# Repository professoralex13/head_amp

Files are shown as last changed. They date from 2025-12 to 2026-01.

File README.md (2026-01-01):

# CosplayCore

TODO: Put information about it here

## IMPORTANT NOTES:
Main board V1.0 runs ADC data from a CODEC into GPIO12 which also serves as a strapping pin. This signal is pulled high by the CODEC resulting in the ESP32 booting with a flash chip voltage is 1.8V which is incorrect.
To work around this, the following command must be run:
```espefuse --port [PORT] burn-efuse XPD_SDIO_REG 1 XPD_SDIO_TIEH 1 XPD_SDIO_FORCE 1```

This overrides the strapping pin so the memory supply voltage is permenantly set at 3.3V.
Until this comand is run and the fuses are burned on the ESP32, it cannot be flashed with any code.

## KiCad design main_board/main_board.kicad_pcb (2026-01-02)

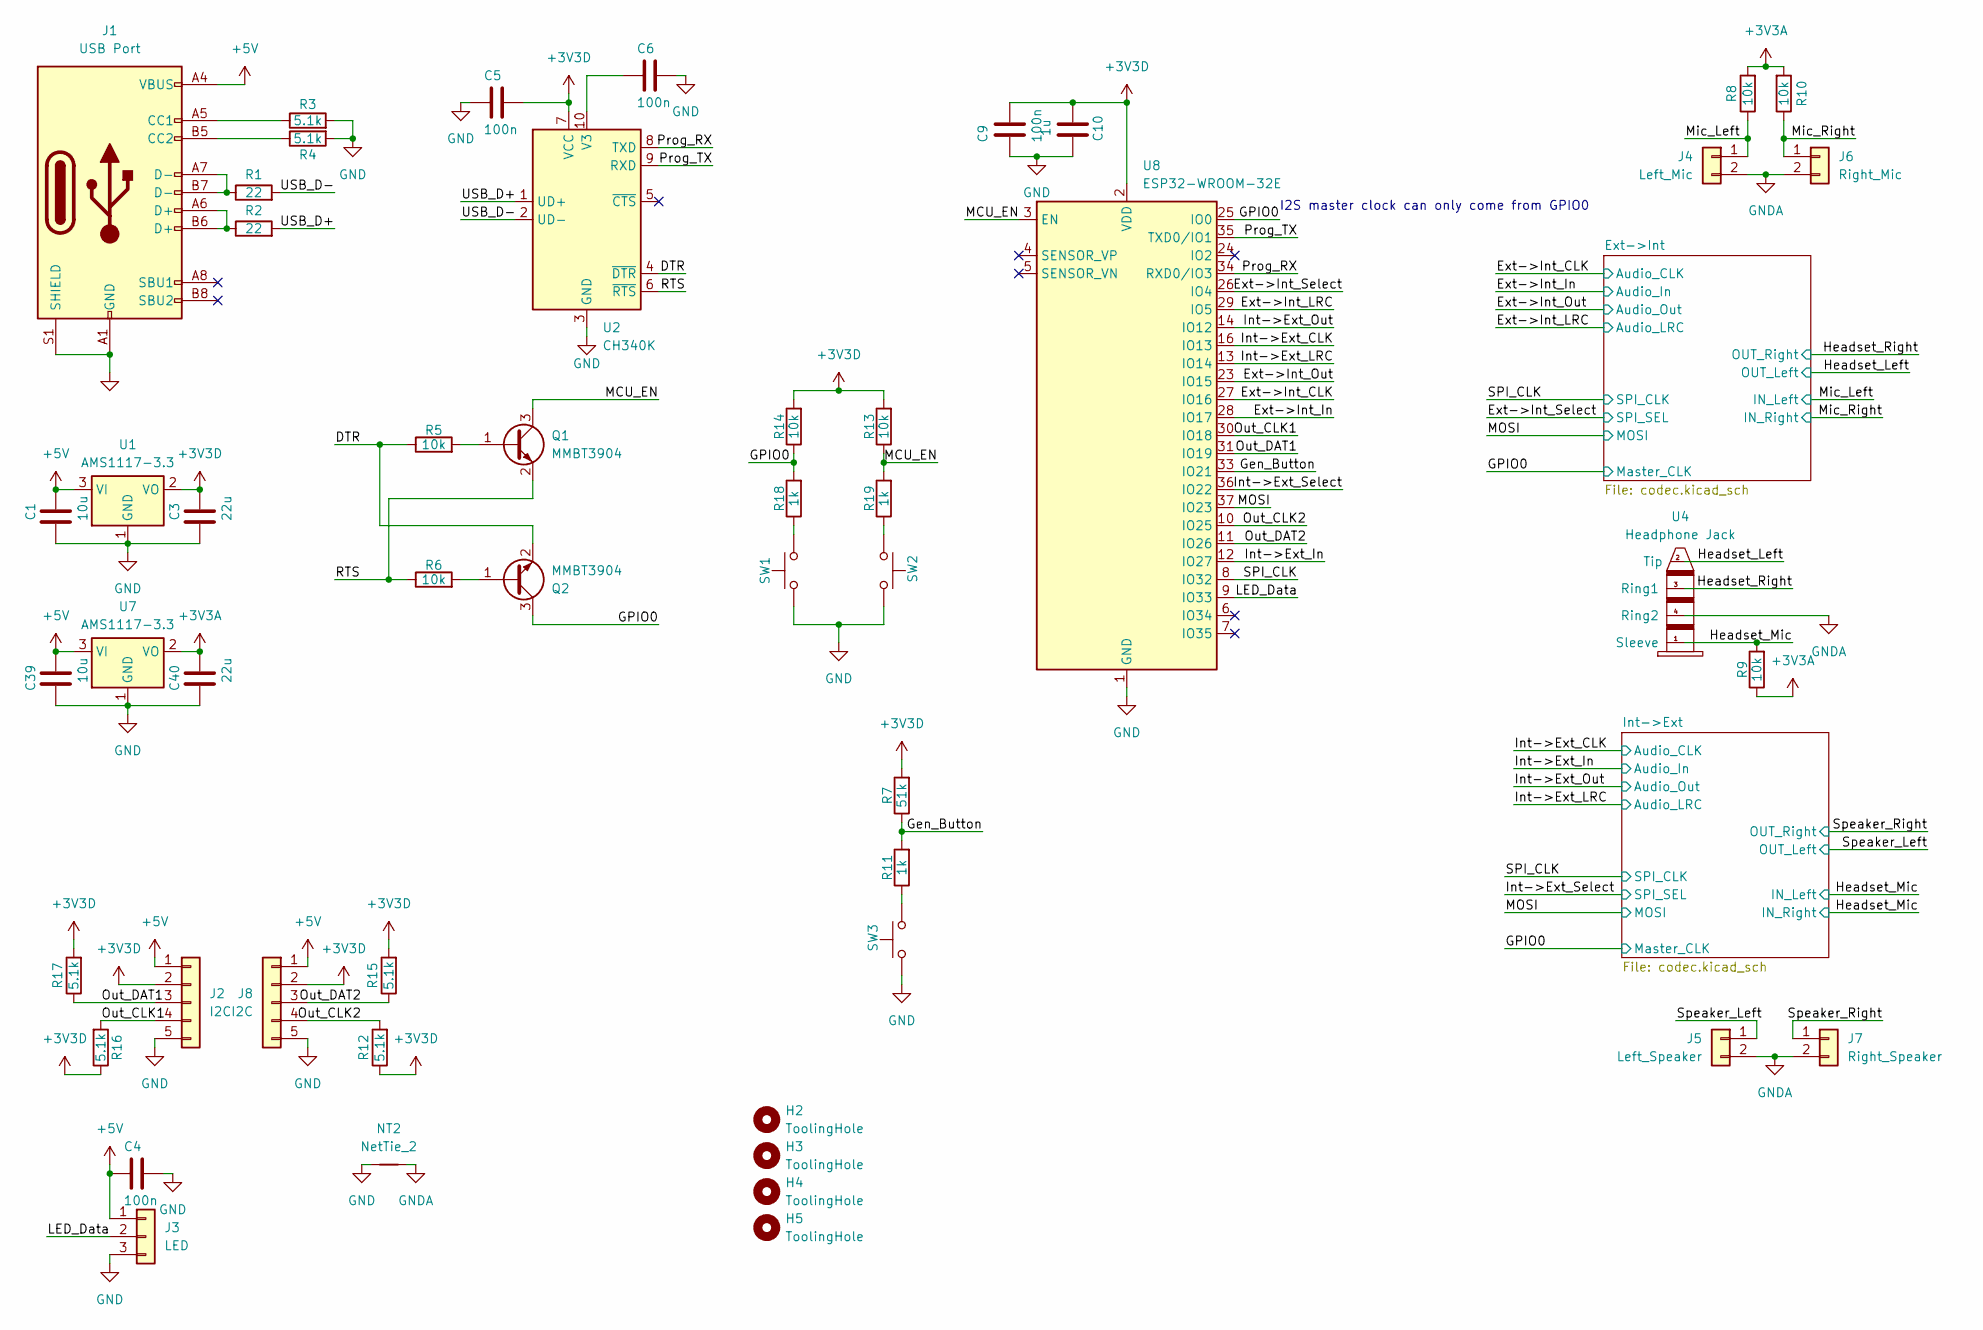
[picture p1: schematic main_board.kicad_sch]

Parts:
C1, C39: 10u; C_0603_1608Metric; LCSC C19702
C3, C40: 22u; C_0603_1608Metric; LCSC C59461
C4, C5, C6: 100n; C_0402_1005Metric; LCSC C307331
C9: 100n; C_0603_1608Metric; LCSC C14663
C10: 1u; C_0603_1608Metric; LCSC C15849
H2, H3, H4, H5: ToolingHole; ToolingHole_1.152mm
J1: USB Port; USB_C_Receptacle_GCT_USB4105-xx-A_16P_TopMnt_Horizontal; LCSC C2927038
J2, J8: I2C; JST_EH_S5B-EH_1x05_P2.50mm_Horizontal; LCSC C265103
J3: LED; JST_EH_S3B-EH_1x03_P2.50mm_Horizontal; LCSC C263754
J4: Left_Mic; JST_EH_S2B-EH_1x02_P2.50mm_Horizontal; LCSC C514173
J5: Left_Speaker; JST_EH_S2B-EH_1x02_P2.50mm_Horizontal; LCSC C514173
J6: Right_Mic; JST_EH_S2B-EH_1x02_P2.50mm_Horizontal; LCSC C514173
J7: Right_Speaker; JST_EH_S2B-EH_1x02_P2.50mm_Horizontal; LCSC C514173
NT2: NetTie_2; NetTie-2_SMD_Pad2.0mm
Q1, Q2: MMBT3904; SOT-23; LCSC C20526
R1, R2: 22; R_0402_1005Metric; LCSC C25092
R3, R4, R12, R15, R16, R17: 5.1k; R_0402_1005Metric; LCSC C25905
R5, R6, R8, R9, R10, R13, R14: 10k; R_0402_1005Metric; LCSC C25744
R7: 51k; R_0402_1005Metric; LCSC C25794
R11, R18, R19: 1k; R_0402_1005Metric; LCSC C11702
SW1, SW2, SW3: SW_Push; SW_SPST_TS-1088-xR020; LCSC C720477
U1, U7: AMS1117-3.3; SOT-223-3_TabPin2; LCSC C6186
U2: CH340K; SSOP-10-1EP_3.9x4.9mm_P1mm_EP2.1x3.3mm; LCSC C18208922
U4: Headphone Jack; PJ-320A; LCSC C2884926
U8: ESP32-WROOM-32E; LCSC C701342

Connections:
+3V3A: C40.2, R8.2, R9.1, R10.2, U7.2 (VO); also elsewhere on the board
+3V3D: C3.2, C5.2, C9.2, C10.1, J2.2, J8.2, R7.2, R12.1, R13.2, R14.2, R15.2, R16.1, R17.2, U1.2 (VO), U2.7 (VCC), U8.2 (VDD); also elsewhere on the board
+5V: C1.2, C4.1, C39.2, J1.A4 (VBUS), J1.A9 (VBUS), J1.B4 (VBUS), J1.B9 (VBUS), J2.1, J3.1, J8.1, U1.3 (VI), U7.3 (VI)
/DTR: Q2.2 (E), R5.1, U2.4 (~DTR)
/Ext->Int_CLK: U8.27 (IO16); also elsewhere on the board
/Ext->Int_In: U8.28 (IO17); also elsewhere on the board
/Ext->Int_LRC: U8.29 (IO5); also elsewhere on the board
/Ext->Int_Out: U8.23 (IO15); also elsewhere on the board
/Ext->Int_Select: U8.26 (IO4); also elsewhere on the board
/GPIO0: Q2.3 (C), R14.1, R18.2, U8.25 (IO0); also elsewhere on the board
/Gen_Button: R7.1, R11.2, U8.33 (IO21)
/Headset_Left: U4.2 (Tip); also elsewhere on the board
/Headset_Mic: R9.2, U4.1 (Sleeve); also elsewhere on the board
/Headset_Right: U4.3 (Ring1); also elsewhere on the board
/Int->Ext_CLK: U8.16 (IO13); also elsewhere on the board
/Int->Ext_In: U8.12 (IO27); also elsewhere on the board
/Int->Ext_LRC: U8.13 (IO14); also elsewhere on the board
/Int->Ext_Out: U8.14 (IO12); also elsewhere on the board
/Int->Ext_Select: U8.36 (IO22); also elsewhere on the board
/LED_Data: J3.2, U8.9 (IO33)
/MCU_EN: Q1.3 (C), R13.1, R19.2, U8.3 (EN)
/MOSI: U8.37 (IO23); also elsewhere on the board
/Mic_Left: J4.1, R8.1; also elsewhere on the board
/Mic_Right: J6.1, R10.1; also elsewhere on the board
/Out_CLK1: J2.4, R16.2, U8.30 (IO18)
/Out_CLK2: J8.4, R12.2, U8.10 (IO25)
/Out_DAT1: J2.3, R17.1, U8.31 (IO19)
/Out_DAT2: J8.3, R15.1, U8.11 (IO26)
/Prog_RX: U2.8 (TXD), U8.34 (RXD0/IO3)
/Prog_TX: U2.9 (RXD), U8.35 (TXD0/IO1)
/RTS: Q1.2 (E), R6.1, U2.6 (~RTS)
/SPI_CLK: U8.8 (IO32); also elsewhere on the board
/Speaker_Left: J5.1; also elsewhere on the board
/Speaker_Right: J7.1; also elsewhere on the board
/USB_D+: R2.2, U2.1 (UD+)
/USB_D-: R1.2, U2.2 (UD-)
GND: C1.1, C3.1, C4.2, C5.1, C6.2, C9.1, C10.2, C39.1, C40.1, J1.A1 (GND), J1.A12 (GND), J1.B1 (GND), J1.B12 (GND), J1.S1 (SHIELD), J2.5, J3.3, J8.5, NT2.1, R3.2, R4.2, SW1.1, SW2.1, SW3.1, U1.1 (GND), U2.3 (GND), U2.11 (GND), U7.1 (GND), U8.1 (GND), U8.15 (GND), U8.38 (GND), U8.39 (GND); also elsewhere on the board
GNDA: J4.2, J5.2, J6.2, J7.2, NT2.2, U4.4 (Ring2); also elsewhere on the board
unnamed: J1.A5 (CC1), R3.1
unnamed: J1.B5 (CC2), R4.1
unnamed: J1.A6 (D+), J1.B6 (D+), R2.1
unnamed: J1.A7 (D-), J1.B7 (D-), R1.1
unnamed: Q1.1 (B), R5.2
unnamed: Q2.1 (B), R6.2
unnamed: R11.1, SW3.2
unnamed: R18.1, SW1.2
unnamed: R19.1, SW2.2
unnamed: C6.1, U2.10 (V3)

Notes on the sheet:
I2S master clock can only come from GPIO0

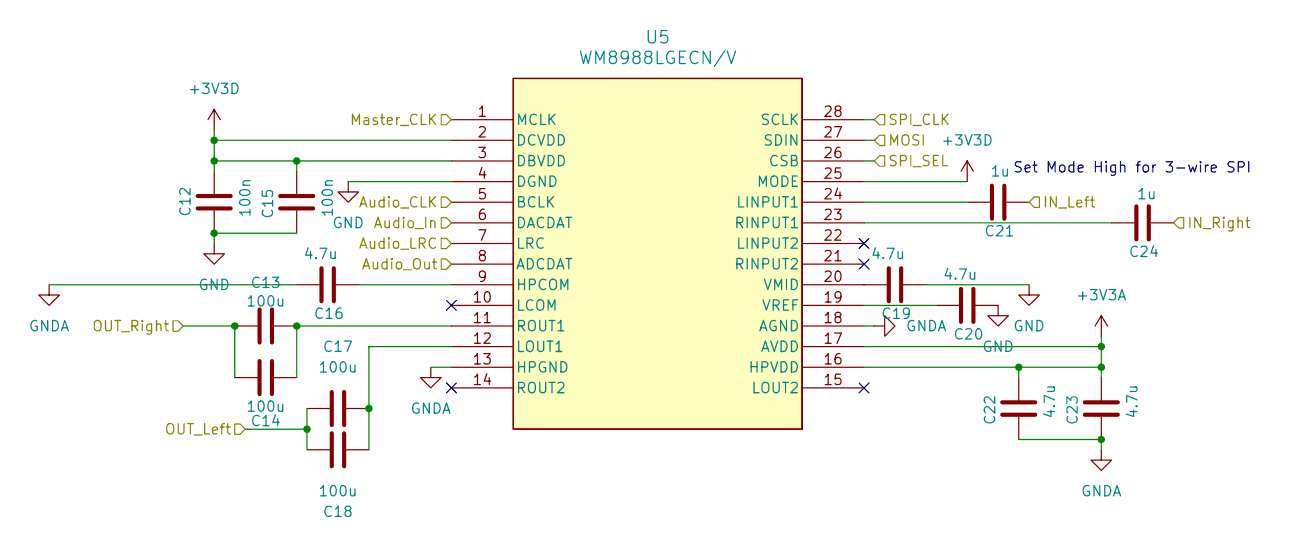
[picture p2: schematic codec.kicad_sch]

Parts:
C12, C15: 100n; C_0402_1005Metric; LCSC C307331
C13, C14, C17, C18: 100u; C_1206_3216Metric; LCSC C15008
C16, C19, C20, C22, C23: 4.7u; C_0402_1005Metric; LCSC C23733
C21, C24: 1u; C_0402_1005Metric; LCSC C52923
U5: WM8988LGECN/V; QFN28_4X4_CIR; LCSC C323851

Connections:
+3V3A: C22.2, C23.2, U5.16 (HPVDD), U5.17 (AVDD); also elsewhere on the board
+3V3D: C12.2, C15.2, U5.2 (DCVDD), U5.3 (DBVDD), U5.25 (MODE); also elsewhere on the board
/GPIO0: U5.1 (MCLK); also elsewhere on the board
/Headset_Mic: C21.1, C24.1; also elsewhere on the board
/Int->Ext_CLK: U5.5 (BCLK); also elsewhere on the board
/Int->Ext_In: U5.6 (DACDAT); also elsewhere on the board
/Int->Ext_LRC: U5.7 (LRC); also elsewhere on the board
/Int->Ext_Out: U5.8 (ADCDAT); also elsewhere on the board
/Int->Ext_Select: U5.26 (CSB); also elsewhere on the board
/MOSI: U5.27 (SDIN); also elsewhere on the board
/SPI_CLK: U5.28 (SCLK); also elsewhere on the board
/Speaker_Left: C17.1, C18.1; also elsewhere on the board
/Speaker_Right: C13.1, C14.1; also elsewhere on the board
GND: C12.1, C15.1, C19.1, C20.1, U5.4 (DGND); also elsewhere on the board
GNDA: C16.2, C22.1, C23.1, U5.13 (HPGND), U5.18 (AGND); also elsewhere on the board
unnamed: C16.1, U5.9 (HPCOM)
unnamed: C21.2, U5.24 (LINPUT1)
unnamed: C17.2, C18.2, U5.12 (LOUT1)
unnamed: C24.2, U5.23 (RINPUT1)
unnamed: C13.2, C14.2, U5.11 (ROUT1)
unnamed: C19.2, U5.20 (VMID)
unnamed: C20.2, U5.19 (VREF)

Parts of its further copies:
C25, C28: 100n; C_0402_1005Metric; LCSC C307331
C26, C27, C30, C31: 100u; C_1206_3216Metric; LCSC C15008
C29, C32, C33, C35, C36: 4.7u; C_0402_1005Metric; LCSC C23733
C34, C37: 1u; C_0402_1005Metric; LCSC C52923
U6: WM8988LGECN/V; QFN28_4X4_CIR; LCSC C323851

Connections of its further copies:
+3V3A: C35.2, C36.2, U6.16 (HPVDD), U6.17 (AVDD); also elsewhere on the board
+3V3D: C25.2, C28.2, U6.2 (DCVDD), U6.3 (DBVDD), U6.25 (MODE); also elsewhere on the board
/Ext->Int_CLK: U6.5 (BCLK); also elsewhere on the board
/Ext->Int_In: U6.6 (DACDAT); also elsewhere on the board
/Ext->Int_LRC: U6.7 (LRC); also elsewhere on the board
/Ext->Int_Out: U6.8 (ADCDAT); also elsewhere on the board
/Ext->Int_Select: U6.26 (CSB); also elsewhere on the board
/GPIO0: U6.1 (MCLK); also elsewhere on the board
/Headset_Left: C30.1, C31.1; also elsewhere on the board
/Headset_Right: C26.1, C27.1; also elsewhere on the board
/MOSI: U6.27 (SDIN); also elsewhere on the board
/Mic_Left: C34.1; also elsewhere on the board
/Mic_Right: C37.1; also elsewhere on the board
/SPI_CLK: U6.28 (SCLK); also elsewhere on the board
GND: C25.1, C28.1, C32.1, C33.1, U6.4 (DGND); also elsewhere on the board
GNDA: C29.2, C35.1, C36.1, U6.13 (HPGND), U6.18 (AGND); also elsewhere on the board
unnamed: C29.1, U6.9 (HPCOM)
unnamed: C34.2, U6.24 (LINPUT1)
unnamed: C30.2, C31.2, U6.12 (LOUT1)
unnamed: C37.2, U6.23 (RINPUT1)
unnamed: C26.2, C27.2, U6.11 (ROUT1)
unnamed: C32.2, U6.20 (VMID)
unnamed: C33.2, U6.19 (VREF)

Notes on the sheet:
Set Mode High for 3-wire SPI

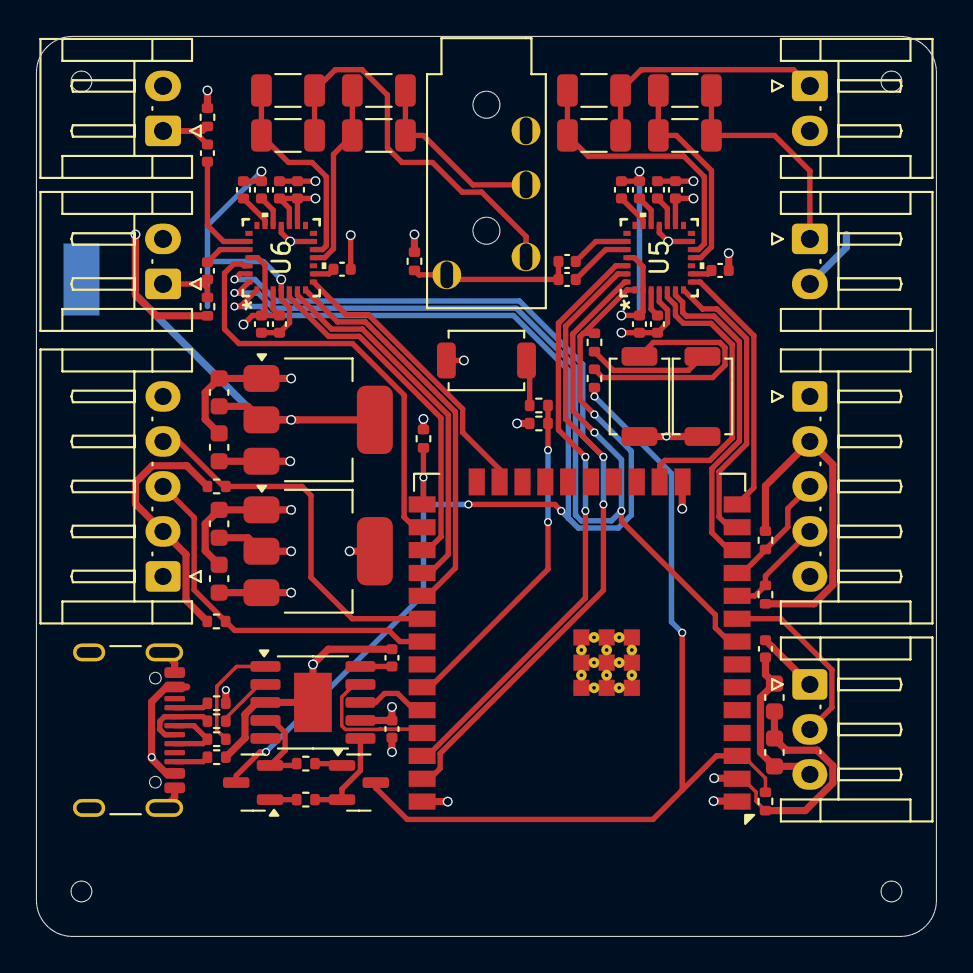
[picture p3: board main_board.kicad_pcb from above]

Board: 4 copper layers, 50.0 x 50.0 mm, 79 parts (1 on the bottom side), 62 nets.

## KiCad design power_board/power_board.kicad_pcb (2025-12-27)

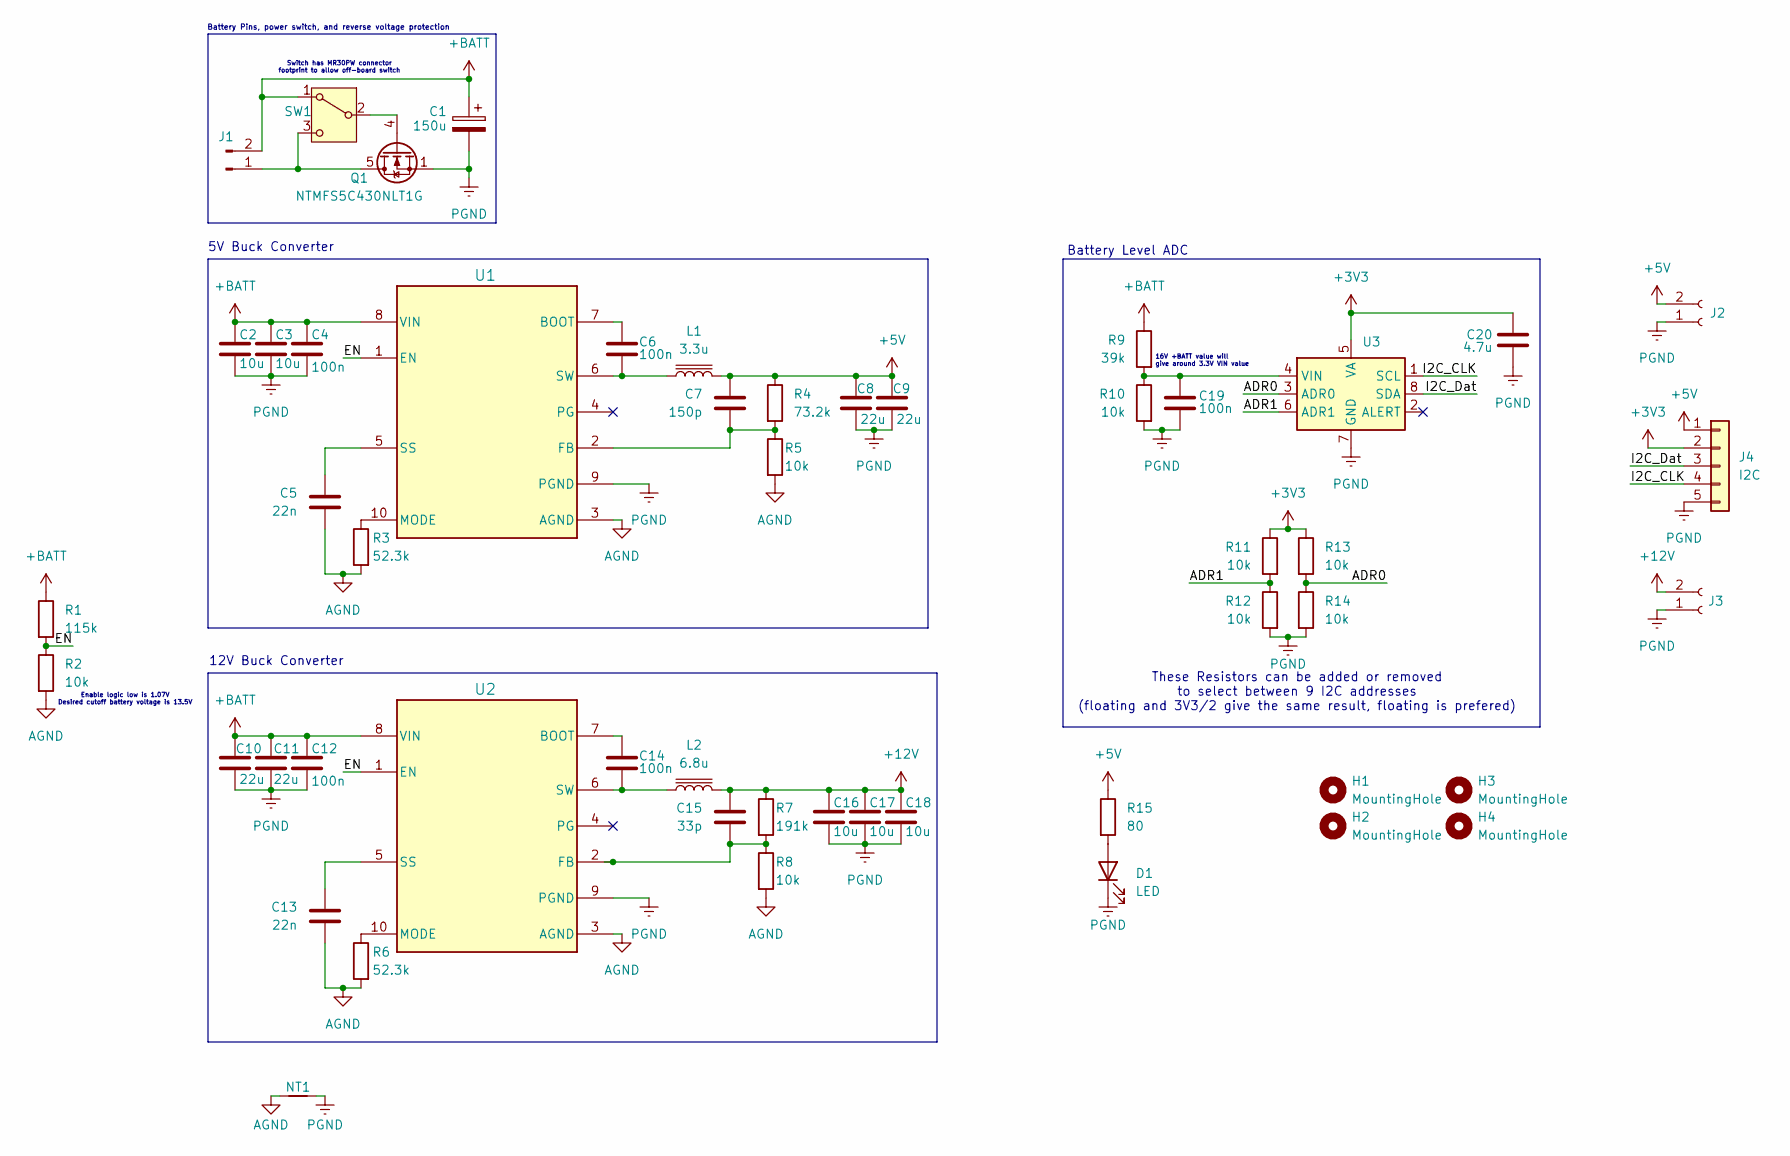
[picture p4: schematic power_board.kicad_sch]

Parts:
C1: 150u; CP_Elec_6.3x7.7; LCSC C2895737
C2, C3, C16, C17, C18: 10u; C_0805_2012Metric; LCSC C5137488
C4, C6, C12, C14: 100n; C_0805_2012Metric; LCSC C5137467
C5, C13: 22n; C_0805_2012Metric; LCSC C5137639
C7: 150p; C_0805_2012Metric; LCSC C7467159
C8, C9, C10, C11: 22u; C_0805_2012Metric; LCSC C7419435
C15: 33p; C_0805_2012Metric; LCSC C7419432
C19: 100n; C_0805_2012Metric; LCSC C476766
C20: 4.7u; C_0805_2012Metric; LCSC C47117445
D1: LED; LED_1206_3216Metric; LCSC C965825
H1, H2, H3, H4: MountingHole; MountingHole_3.2mm_M3
J1: Conn_01x02_Pin; AMASS_XT60PW-M_1x02_P7.20mm_Horizontal; LCSC C98732
J2, J3: Conn_01x02_Socket; AMASS_XT30PW-F_1x02_P2.50mm_Horizontal; LCSC C2913282
J4: I2C; JST_EH_S5B-EH_1x05_P2.50mm_Horizontal; LCSC C265103
L1: 3.3u; L_APV_APH1030; LCSC C845075
L2: 6.8u; L_TaiTech_TMPC1265_13.5x12.5mm; LCSC C2847562
NT1: NetTie_2; NetTie-2_SMD_Pad0.5mm
Q1: NTMFS5C430NLT1G; ONSemi_SO-8FL_488AA; LCSC C36499169
R1: 115k; R_0805_2012Metric; LCSC C2933289
R2, R5, R8, R10: 10k; R_0805_2012Metric; LCSC C2907219
R3, R6: 52.3k; R_0805_2012Metric; LCSC C2933465
R4: 73.2k; R_0805_2012Metric; LCSC C5713314
R7: 191k; R_0805_2012Metric; LCSC C3000728
R9: 39k; R_0805_2012Metric; LCSC C2933691
R11, R12, R13, R14: 10k; R_1206_3216Metric; LCSC C2907423
R15: 80; R_1206_3216Metric; LCSC C2907540
SW1: SW_SPDT; AMASS_MR30PW-FB_1x03_P3.50mm_Horizontal; LCSC C19268035
U1, U2: TPS56A37RPAR; RPA0010A-MFG; LCSC C22392669
U3: ADC081C021CIMM; MSOP-8_3x3mm_P0.65mm; LCSC C206013

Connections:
+3V3: C20.1, J4.2, R11.1, R13.1, U3.5 (VA)
+5V: C7.1, C8.1, C9.1, J2.2, J4.1, L1.2, R4.1, R15.1
+12V: C15.1, C16.1, C17.1, C18.1, J3.2, L2.2, R7.1
+BATT: C1.1, C2.1, C3.1, C4.1, C10.1, C11.1, C12.1, J1.2, R1.1, R9.1, SW1.1 (A), U1.8 (VIN), U2.8 (VIN)
/ADR0: R13.2, R14.1, U3.3 (ADR0)
/ADR1: R11.2, R12.1, U3.6 (ADR1)
/EN: R1.2, R2.1, U1.1 (EN), U2.1 (EN)
/I2C_CLK: J4.4, U3.1 (SCL)
/I2C_Dat: J4.3, U3.8 (SDA)
AGND: C5.2, C13.2, NT1.1, R2.2, R3.2, R5.2, R6.2, R8.2, U1.3 (AGND), U2.3 (AGND)
unnamed: D1.2 (A), R15.2
unnamed: J1.1, Q1.5 (D), SW1.3 (C)
unnamed: Q1.4 (G), SW1.2 (B)
unnamed: C6.2, U1.7 (BOOT)
unnamed: C7.2, R4.2, R5.1, U1.2 (FB)
unnamed: R3.1, U1.10 (MODE)
unnamed: C5.1, U1.5 (SS)
unnamed: C6.1, L1.1, U1.6 (SW)
unnamed: C14.2, U2.7 (BOOT)
unnamed: C15.2, R7.2, R8.1, U2.2 (FB)
unnamed: R6.1, U2.10 (MODE)
unnamed: C13.1, U2.5 (SS)
unnamed: C14.1, L2.1, U2.6 (SW)
unnamed: C19.2, R9.2, R10.1, U3.4 (VIN)
PGND: C1.2, C2.2, C3.2, C4.2, C8.2, C9.2, C10.2, C11.2, C12.2, C16.2, C17.2, C18.2, C19.1, C20.2, D1.1 (K), J2.1, J3.1, J4.5, NT1.2, Q1.1 (S), Q1.2 (S), Q1.3 (S), R10.2, R12.2, R14.2, U1.9 (PGND), U2.9 (PGND), U3.7 (GND)

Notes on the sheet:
5V Buck Converter
Battery Level ADC
Switch has MR30PW connector footprint to allow off-board switch
12V Buck Converter
These Resistors can be added or removed to select between 9 I2C addresses (floating and 3V3/2 give the same result, floating is prefered)
16V +BATT value will give around 3.3V VIN value
Enable logic low is 1.07V Desired cutoff battery voltage is 13.5V
Battery Pins, power switch, and reverse voltage protection

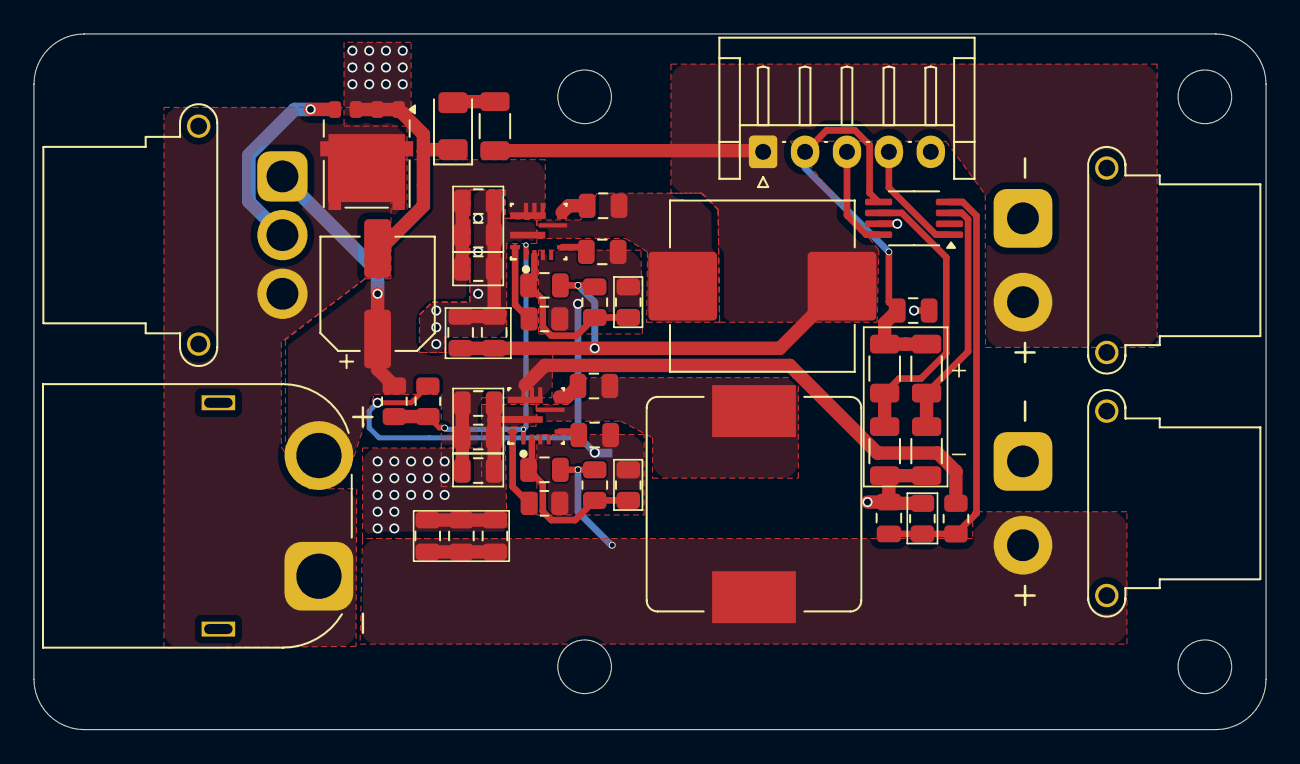
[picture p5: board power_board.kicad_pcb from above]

Board: 2 copper layers, 73.5 x 41.5 mm, 52 parts (1 on the bottom side), 25 nets.

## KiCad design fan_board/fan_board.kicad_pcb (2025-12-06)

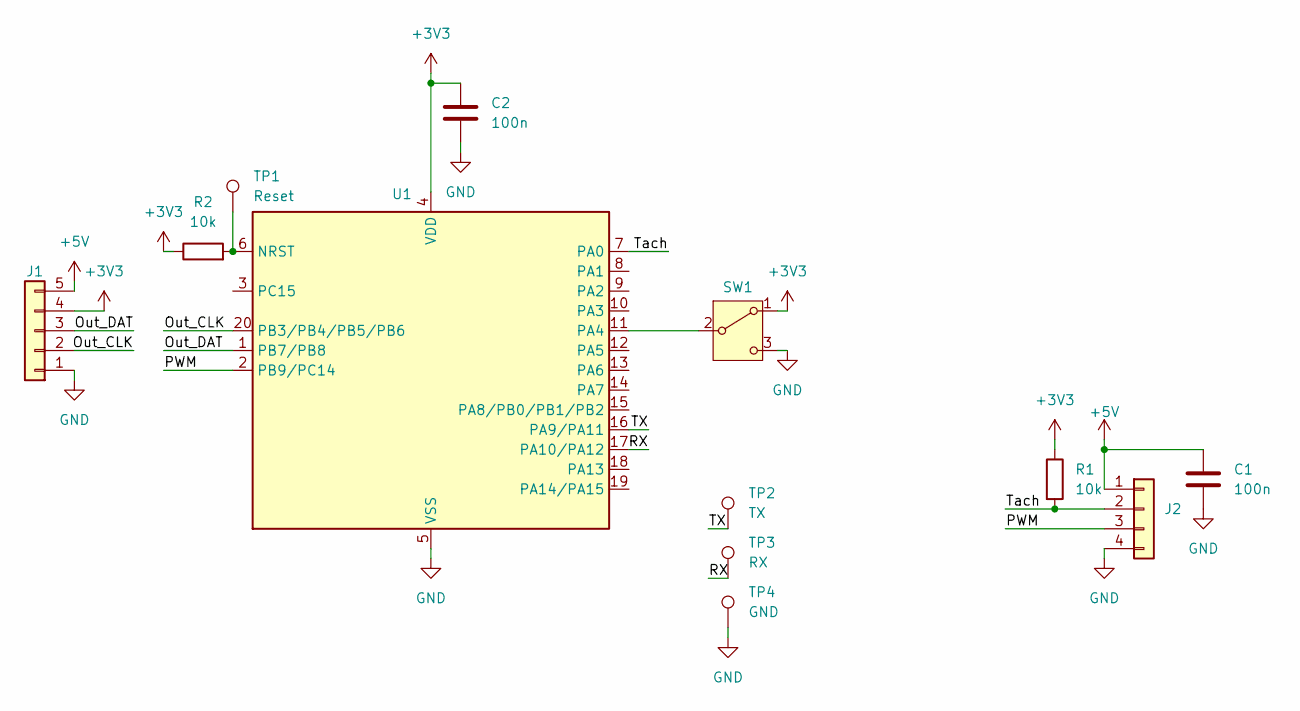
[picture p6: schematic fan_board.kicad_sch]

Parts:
C1, C2: 100n; C_1206_3216Metric_Pad1.33x1.80mm_HandSolder; LCSC C24497
J1: Conn_01x05; JST_EH_S5B-EH_1x05_P2.50mm_Horizontal; LCSC C265103
J2: Conn_01x04; JST_EH_S4B-EH_1x04_P2.50mm_Horizontal; LCSC C265068
R1, R2: 10k; R_1206_3216Metric_Pad1.30x1.75mm_HandSolder; LCSC C17902
SW1: SW_SPDT; Nidec_Copal_CAS-120A; LCSC C5619548
TP1: Reset; TestPoint_Pad_3.0x3.0mm
TP2: TX; TestPoint_Pad_3.0x3.0mm
TP3: RX; TestPoint_Pad_3.0x3.0mm
TP4: GND; TestPoint_Pad_3.0x3.0mm
U1: STM32G030F6Px; TSSOP-20_4.4x6.5mm_P0.65mm; LCSC C529330

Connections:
+3V3: C2.1, J1.4, R1.1, R2.1, SW1.1 (A), U1.4 (VDD)
+5V: C1.1, J1.5, J2.1
/Out_CLK: J1.2, U1.20 (PB3/PB4/PB5/PB6)
/Out_DAT: J1.3, U1.1 (PB7/PB8)
/PWM: J2.3, U1.2 (PB9/PC14)
/RX: TP3.1, U1.17 (PA10/PA12)
/TX: TP2.1, U1.16 (PA9/PA11)
/Tach: J2.2, R1.2, U1.7 (PA0)
GND: C1.2, C2.2, J1.1, J2.4, SW1.3 (C), TP4.1, U1.5 (VSS)
unnamed: SW1.2 (B), U1.11 (PA4)
unnamed: R2.2, TP1.1, U1.6 (NRST)

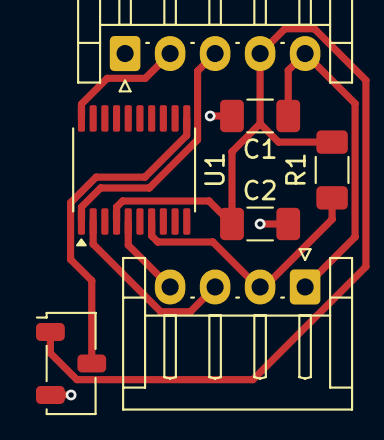
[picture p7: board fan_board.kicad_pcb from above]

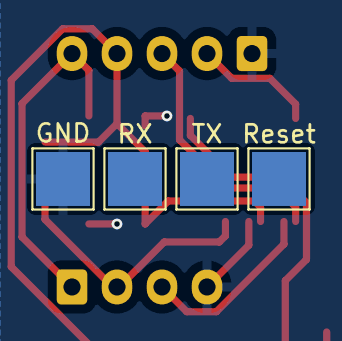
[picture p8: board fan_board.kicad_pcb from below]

Board: 2 copper layers, 11 parts (4 on the bottom side), 11 nets.

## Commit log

2025-09-09 Route PCB :3
    [head_amp.kicad_pcb, head_amp.kicad_sch]
2025-10-27 Lots of stuff
    [codec.kicad_sch, head_amp.kicad_pcb, head_amp.kicad_sch]
2025-10-28 More stuff
    [codec.kicad_sch, head_amp.kicad_pcb, head_amp.kicad_sch]
2025-10-28 started compact layout
    [codec.kicad_sch, head_amp.kicad_pcb, head_amp.kicad_sch]
2025-10-29 feat: start hat version
    [codec.kicad_sch, head_amp.kicad_pcb, head_amp.kicad_sch]
2025-10-30 More capacitor layed
    [codec.kicad_sch, head_amp.kicad_pcb, head_amp.kicad_sch]
2025-10-30 Remove conflict silkscreen
    [head_amp.kicad_pcb, head_amp.kicad_sch]
2025-11-01 feat: pretty much done
    [codec.kicad_sch, head_amp.kicad_pcb, head_amp.kicad_sch]
2025-11-03 feat: overhaul
    [codec.kicad_sch, head_amp.kicad_pcb, head_amp.kicad_sch]
2025-11-06 add 3d models and tooling holes
    [head_amp.kicad_pcb, head_amp.kicad_sch]
2025-11-06 Add holes and generic control button
    [head_amp.kicad_pcb, head_amp.kicad_sch]
2025-11-25 Add second expansion port
    [codec.kicad_sch, head_amp.kicad_pcb, head_amp.kicad_sch]
2025-11-25 Remove unused libraries
    [LM124DR.step]
2025-11-25 Move to subproject
    [codec.kicad_sch, main_board.kicad_pcb, main_board.kicad_sch]
2025-11-25 fix: missing I2C pullup resistors
    [main_board.kicad_pcb, main_board.kicad_sch]
2025-12-06 Started breakout boards
    [button_board.kicad_pcb, button_board.kicad_sch, fan_board.kicad_pcb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]
2025-12-20 finish v1.0
    [codec.kicad_sch, main_board.kicad_pcb, main_board.kicad_sch]
2025-12-26 feat: initial power board
    [power_board.kicad_pcb, power_board.kicad_sch]
2025-12-26 feat: 10A converters
    [power_board.kicad_pcb, power_board.kicad_sch]
2025-12-27 larger power traces
    [power_board.kicad_pcb, power_board.kicad_sch]
2025-12-27 improve power fill thickness
    [power_board.kicad_pcb]
2026-01-01 Add README
    Added important notes regarding the main board V1.0 and ADC data handling.
2026-01-02 reroute SPI (non output pin issue)
    [main_board.kicad_pcb, main_board.kicad_sch]
